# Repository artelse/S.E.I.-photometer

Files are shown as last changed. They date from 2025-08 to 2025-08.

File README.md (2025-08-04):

# S.E.I.-photometer
A lamp replacement board for the vintage S.E.I. photometer.

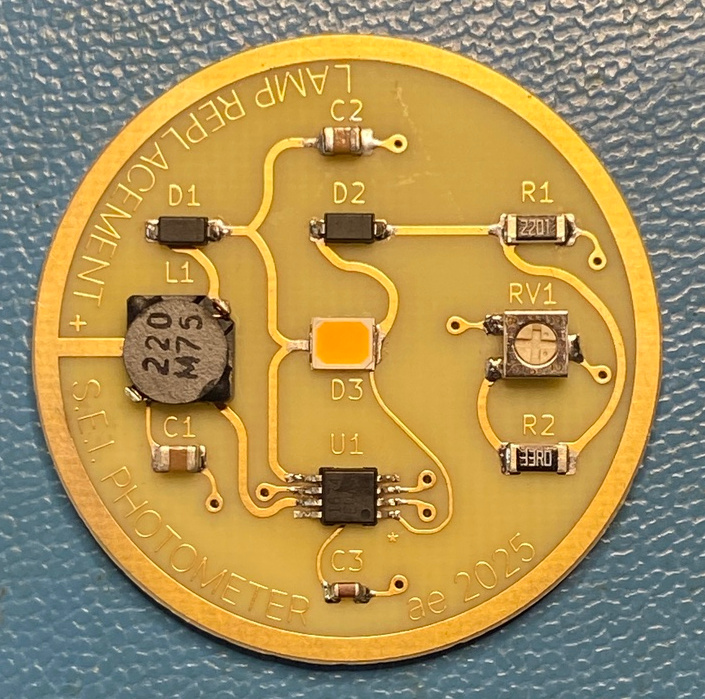
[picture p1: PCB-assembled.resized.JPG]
Assembled PCB


A replacement light source for the vintage S.E.I. photometer was created by someone with the name Huw[^1]. Here the schematic and board are recreated in Kicad. Datasheets for the components are included as well as any documentation on the S.E.I. photometer that we could find.

For fun, and to stay a bit with the times, I used the *Round Tracks* plugin for the PCB layout. Further, the board has no solder mask or silkscreen, but has full board ENIG gold finish for good connectivity with the battery and enclosure.

I case one needs a board, am happy to send you one at cost. 

[^1]: See Documents folder for details

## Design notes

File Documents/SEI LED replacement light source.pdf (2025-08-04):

The SEI LED replacement light source.

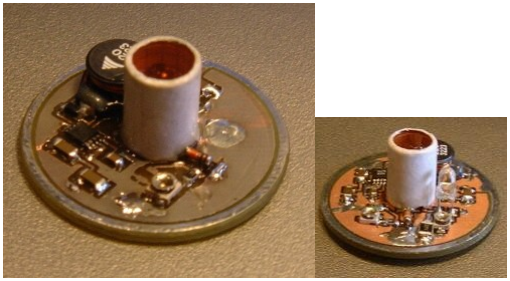
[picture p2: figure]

Yer bog standard SEI LED | vanity version with extra LED

I had a think......
One white led filtered to about 3000K and for the deluxe version an extra (adjustable) led just to illuminate the photocell for the vain who want a working meter, there is only one of these in the whole world and it is owned by Roger Hicks.

For the filtering Lee filters had the solution and gave me a swatch of some 250 lighting filters, one turned out to be perfect. The LED comes from Marl, a bit pricey at 2UKP each but guaranteed colour temp. and quite bright, so bright the datasheet warns of eye damage!, distributed by Farnell.

Temperature compensation
The LED has a negative (i.e. dimmer when hotter) temperature coefficient, so when it's sunny and hot you would overexpose (perfect!) a bit, the silicon diode (circuit D2) also has a negative coefficient and is put in series with current detecting resistor chain (circuit R1, 2 and P1) so the current rises with temperature. Tests using my freezer and oven at about -10C, 20C and +40C (that was quite hot to hold) revealed no measurable change at all. Certainly within the useable accuracy of the SEI (about 1/4 of a division of error when setting the match) thats about 1/12th stop (6%). Interestingly my L-308 moved from f8.0 at 20C to f8.2 at -10C.

The electronics.....
A MAX1674 converts the 1.5V cell to 4-5V for the LED, the current through the LED controls the output and is temperature compensated by the silicon diode.

The MAX1674 circuit takes 40mA, this will give 450 hours using a 'D' cell. The fun bit is soldering the MAX1674, it's in a uMAX pack, the legs are on a 20thou (mils for the Americans, 0.5mm for the Europeans) pitch, thats a 10thou gap. I have three 1674s as samples from Maxim, they have survived de-re-soldering twice so far. The choke is a bit big for the current required but the 1674 has a 1A limit internaly, I will use the 1675 with a 500mA limit and a smaller choke for the next lot. Assuming anybody wants one (or more).

To buy one of these hand built pieces of engineering joy, fully calibrated, mail me huw@huws.homelinux.org (https://web.archive.org/web/20180723050149/mailto:huw@huws.homelinux.org)

Circuit diagram for MKII (https://web.archive.org/web/20180723050149fw_/http:/www.huwswebthing.talktalk.net/seiledcct.gif)

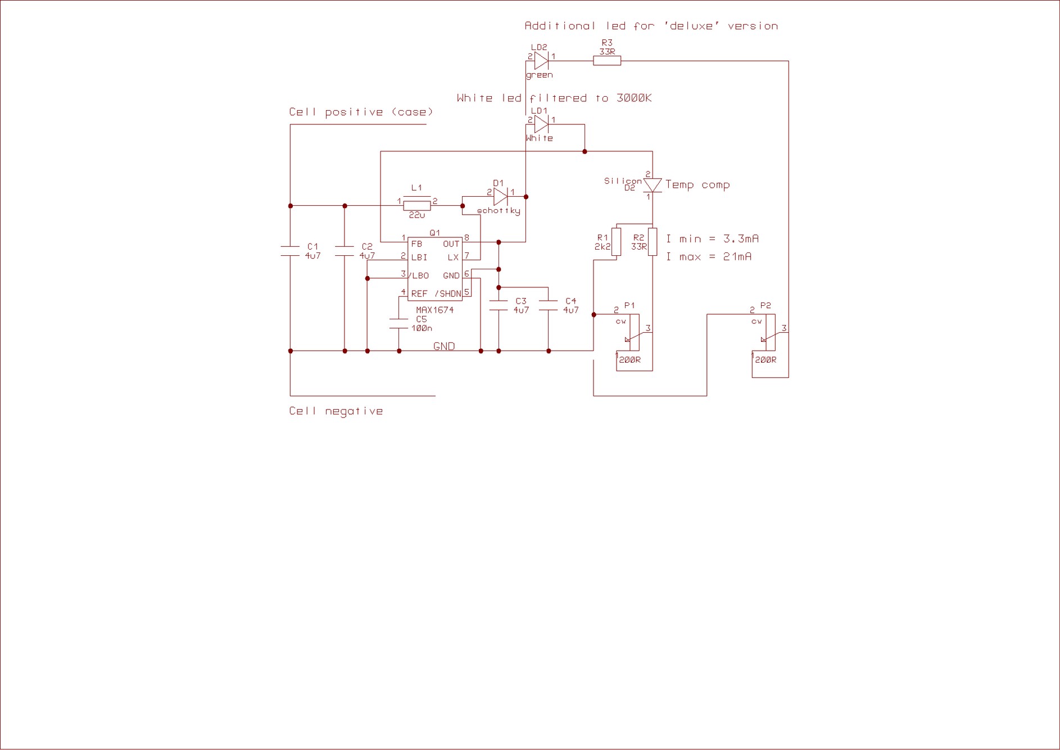
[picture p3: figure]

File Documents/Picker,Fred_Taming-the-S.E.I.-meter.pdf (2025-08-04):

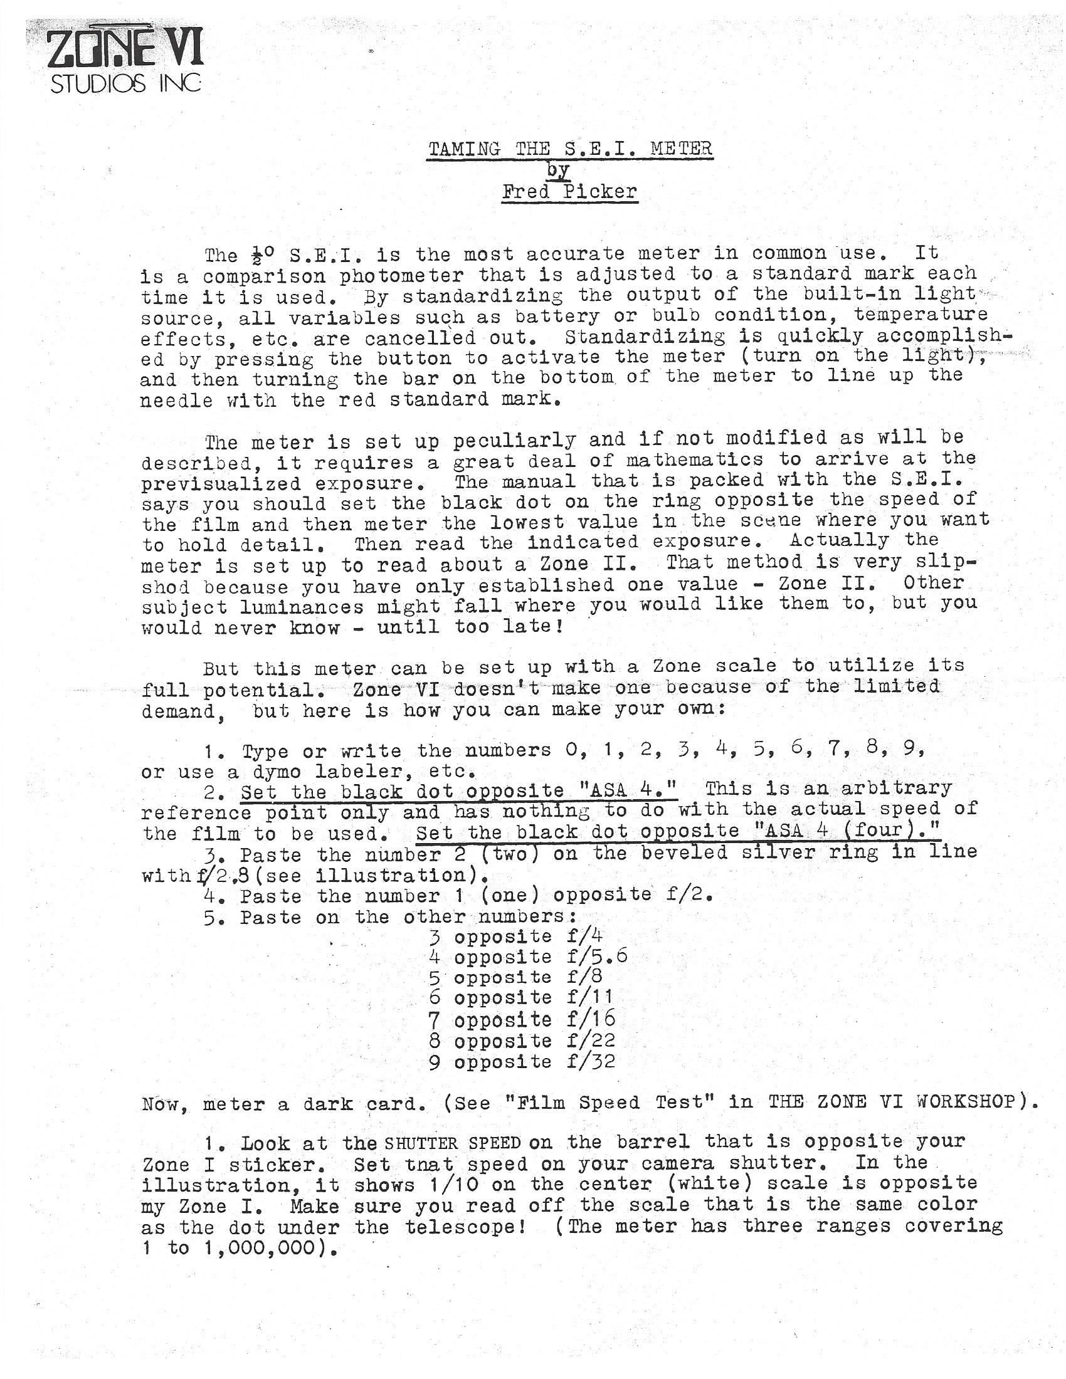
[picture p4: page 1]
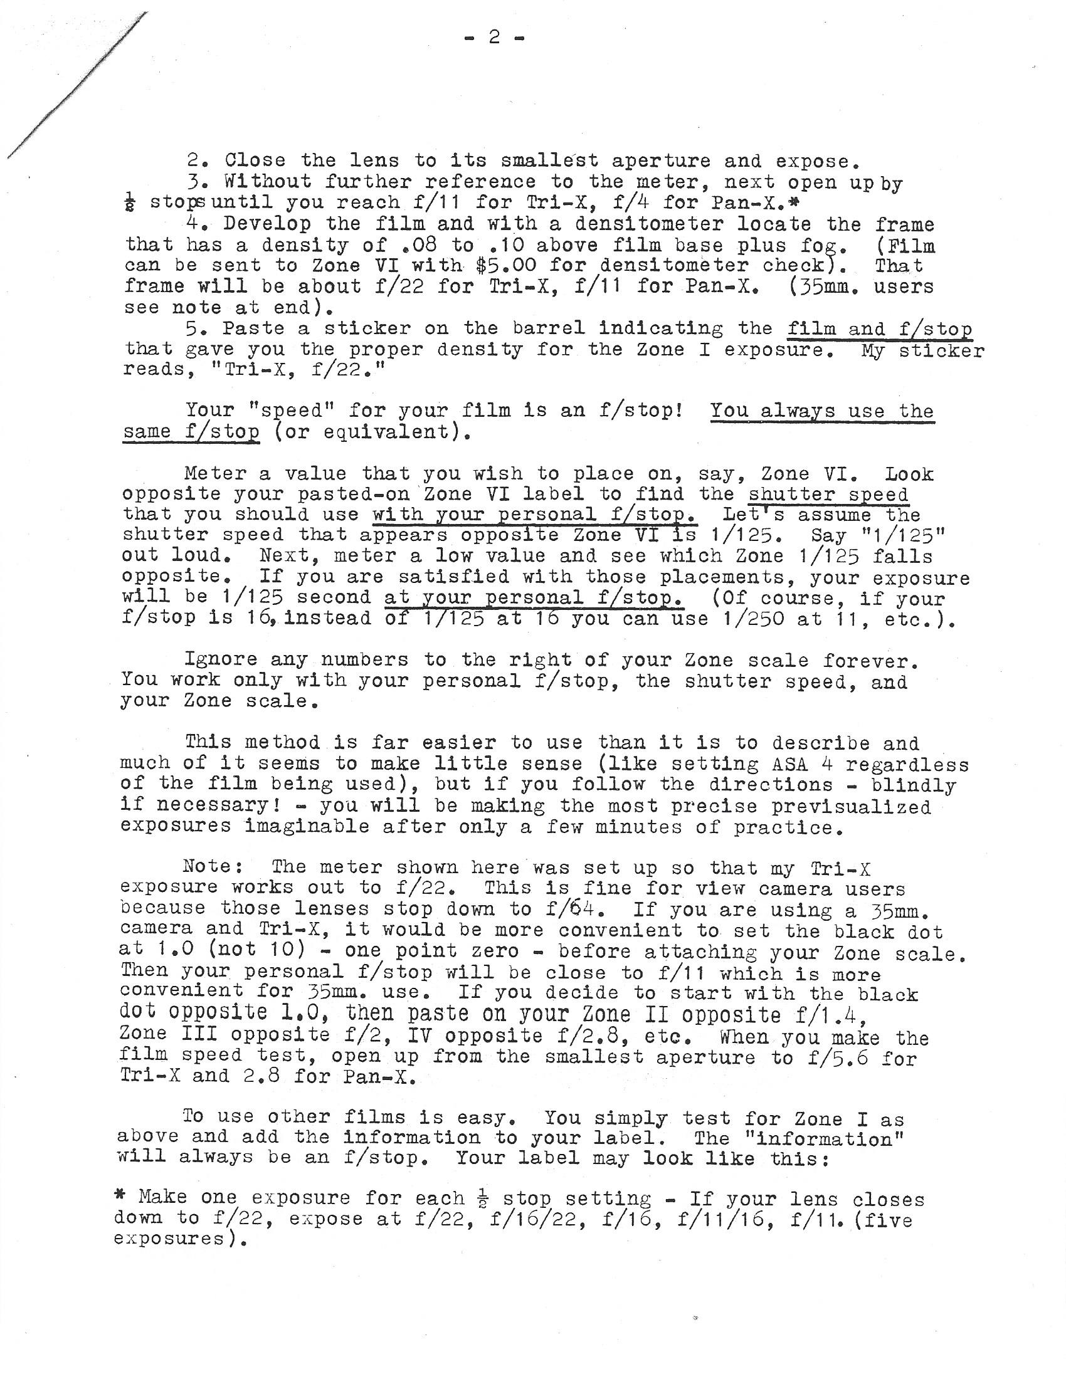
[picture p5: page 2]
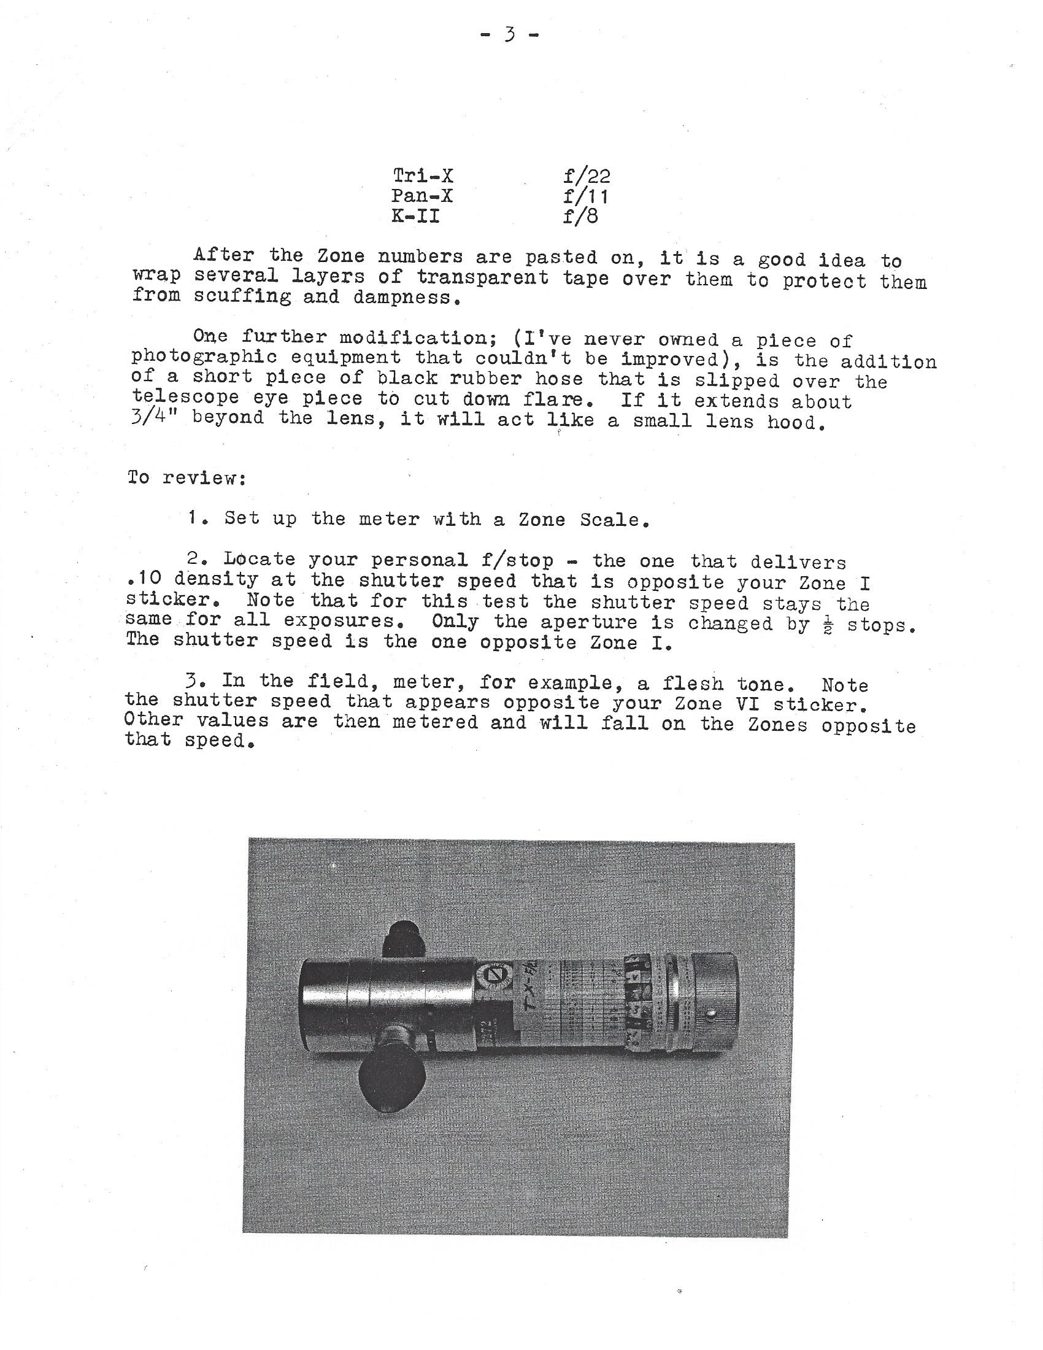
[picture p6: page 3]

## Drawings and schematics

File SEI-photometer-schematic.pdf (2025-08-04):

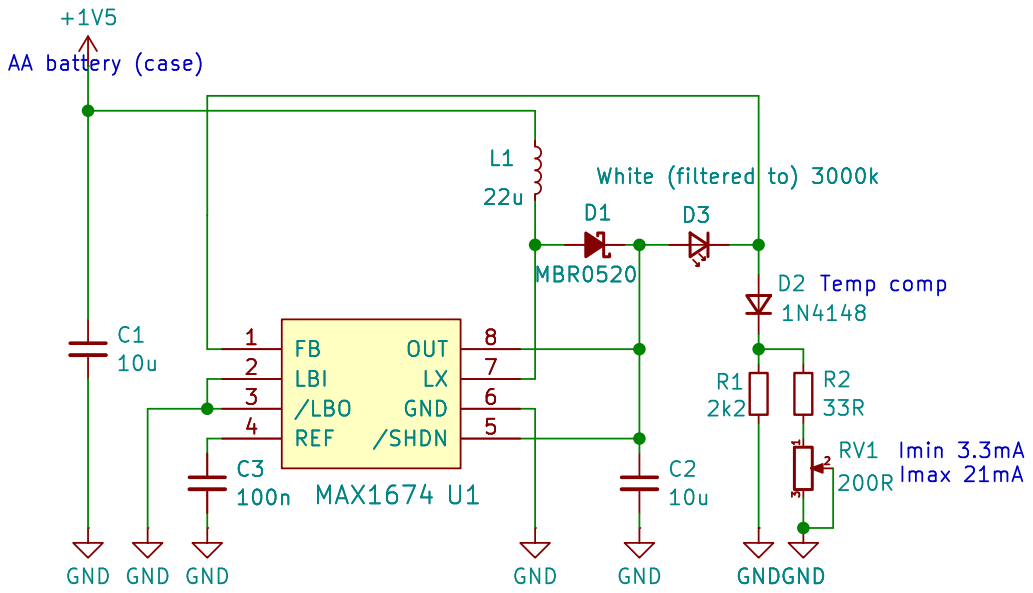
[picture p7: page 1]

Id: 1/1 Title: S.E.I. Photometer - Lamp Replacement File: SEI-photometer.kicad_sch Sheet: /

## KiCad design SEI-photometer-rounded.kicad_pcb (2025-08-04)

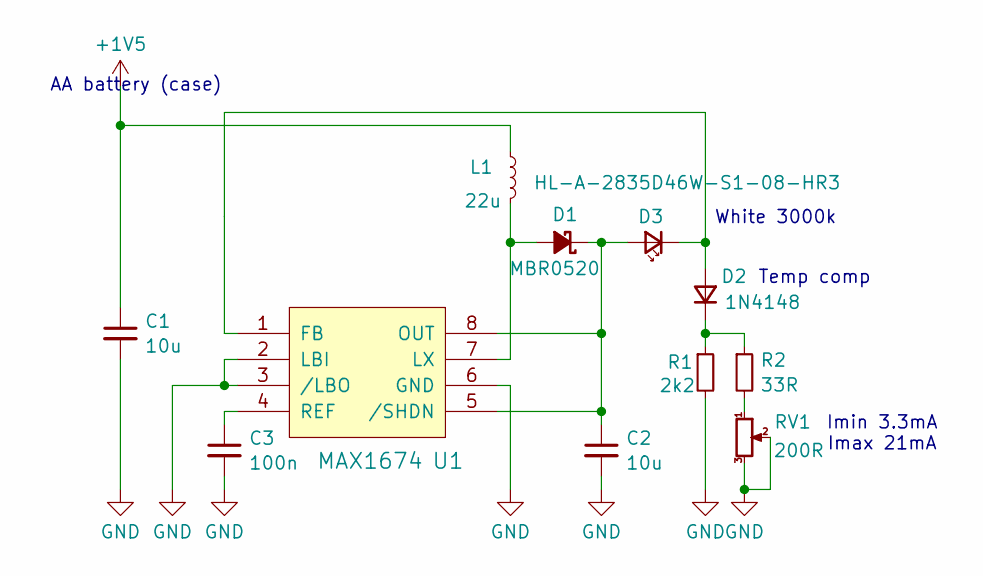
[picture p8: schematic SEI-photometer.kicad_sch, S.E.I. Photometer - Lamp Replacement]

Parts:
C1, C2: 10u; C_0805_2012Metric
C3: 100n; C_0603_1608Metric
D1: MBR0520; D_SOD-123
D2: 1N4148; D_SOD-123
D3: HL-A-2835D46W-S1-08-HR3; LED_Everlight-SMD3528_3.5x2.8mm_67-21ST
L1: 22u; L_Coilcraft_LPS5030
R1: 2k2; R_1206_3216Metric
R2: 33R; R_1206_3216Metric
RV1: 200R; Potentiometer_Bourns_PVG3G_Horizontal
U1: MAX1674; 21-0036_U8-1_MXM

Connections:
+1V5: C1.1, L1.1
GND: C1.2, C2.2, C3.2, R1.2, RV1.2, RV1.3, U1.2 (LBI), U1.3 (/LBO), U1.6 (GND)
unnamed: D1.2 (A), L1.2, U1.7 (LX)
unnamed: C2.1, D1.1 (K), D3.2 (A), U1.5 (/SHDN), U1.8 (OUT)
unnamed: D2.2 (A), D3.1 (K), U1.1 (FB)
unnamed: D2.1 (K), R1.1, R2.1
unnamed: R2.2, RV1.1
unnamed: C3.1, U1.4 (REF)

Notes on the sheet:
Imin 3.3mA Imax 21mA
AA battery (case)
Temp comp
White 3000k

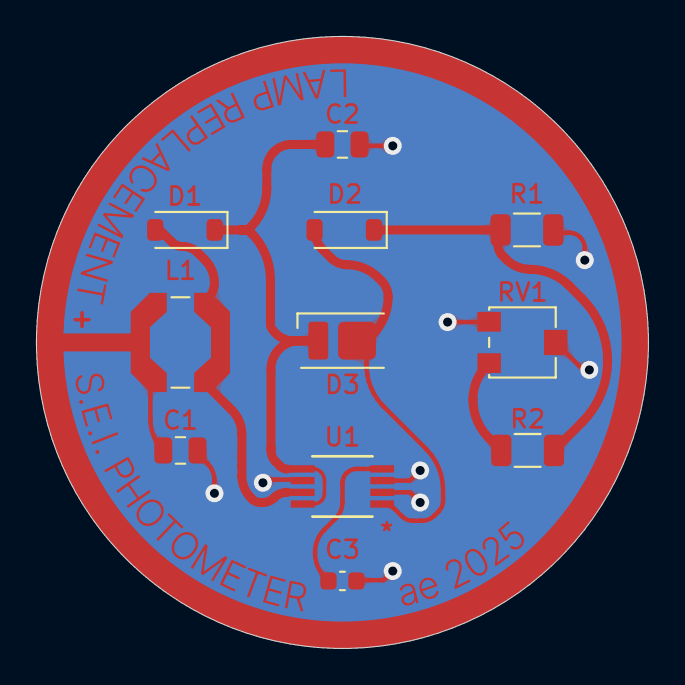
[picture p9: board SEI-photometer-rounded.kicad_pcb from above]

Board: 2 copper layers, 34.0 x 34.0 mm, 11 parts (0 on the bottom side), 8 nets.

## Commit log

2025-08-04 Added project files.
    [SEI-photometer-rounded.kicad_pcb, SEI-photometer.kicad_sch]
2025-08-04 Deleted S.E.I. schematic.pdf
2025-08-04 Rename SEI LED replacement light source.pdf to Documents/SEI LED replacement light source.pdf
